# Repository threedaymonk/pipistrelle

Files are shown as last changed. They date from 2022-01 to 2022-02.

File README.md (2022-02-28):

# Pipistrelle

A low-cost multi-function Eurorack module based on the Seeeduino Xiao module.

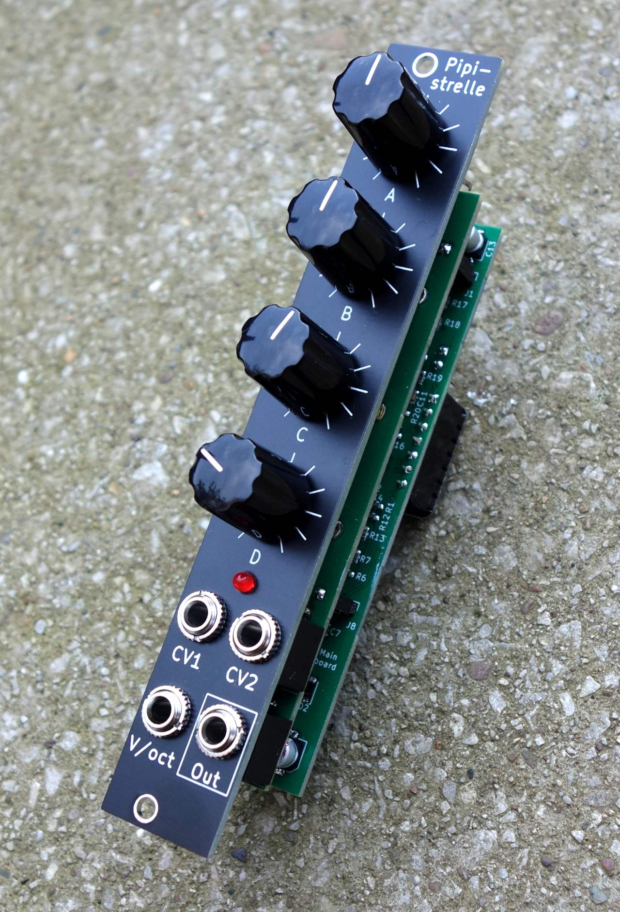
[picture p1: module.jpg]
Assembled module


This module can be built for as little as £20 (based on an order of 25 with
surface mount parts mostly assembled by JLCPCB) and provides:

- 4 potentiometers
- 2 CV inputs
- 1 V/oct input
- 1 DC-coupled output
- Output range ±5V or ±8V selected via jumper

Inputs are 12 bit, output is 10 bit.

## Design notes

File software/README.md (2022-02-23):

# Software for the Pipistrelle

All software is developed using [PlatformIO](https://platformio.org/) with the
Arduino toolchain for the Seeeduino Xiao.

# Calibration

To initiate calibration, turn all the pots to minimum, connect a patch cable
from **Out** to **CV1**, and power on the module.

The LED flashes.

Send 1V from a known source to **V/oct** and turn **A** fully clockwise.

The LED flashes twice.

Send 3V from a known source to **V/oct** and turn **B** fully clockwise.

The oscillator will now boot as normal.

## X-Y Oscillator

This oscillator generates sine, triangle, saw, and square waves and blends
between them using the C and D pots and CV inputs.

- **Pot A**: Coarse tune (C0 + 6 octaves)
- **Pot B**: Fine tune (+/- 1/2 octave)
- **Pot C + CV 1**: X
- **Pot D + CV 2**: Y

X and Y morph between waveforms thus:

     sine  --> triangle
      |           |
      v           v
    square -->   saw

## Supersaw

7 detuned saw waves and a square wave sub-oscillator an octave below

- **Pot A**: Coarse tune (C0 + 6 octaves)
- **Pot B**: Fine tune (+/- 1/2 octave)
- **Pot C + CV 1**: Detune amount
- **Pot D + CV 2**: Sub oscillator level

## Wavetable

Wavetable oscillator panning around 64 256-sample wavetables in an 8 by 8
plane.

- **Pot A**: Coarse tune (C0 + 6 octaves)
- **Pot B**: Fine tune (+/- 1/2 octave)
- **Pot C + CV 1**: X
- **Pot D + CV 2**: Y

## ADSR

ADSR envelope generator

- **Pot A**: Attack
- **Pot B + CV 1**: Decay
- **Pot C**: Sustain
- **Pot D + CV 2**: Release
- **V/oct**: Gate

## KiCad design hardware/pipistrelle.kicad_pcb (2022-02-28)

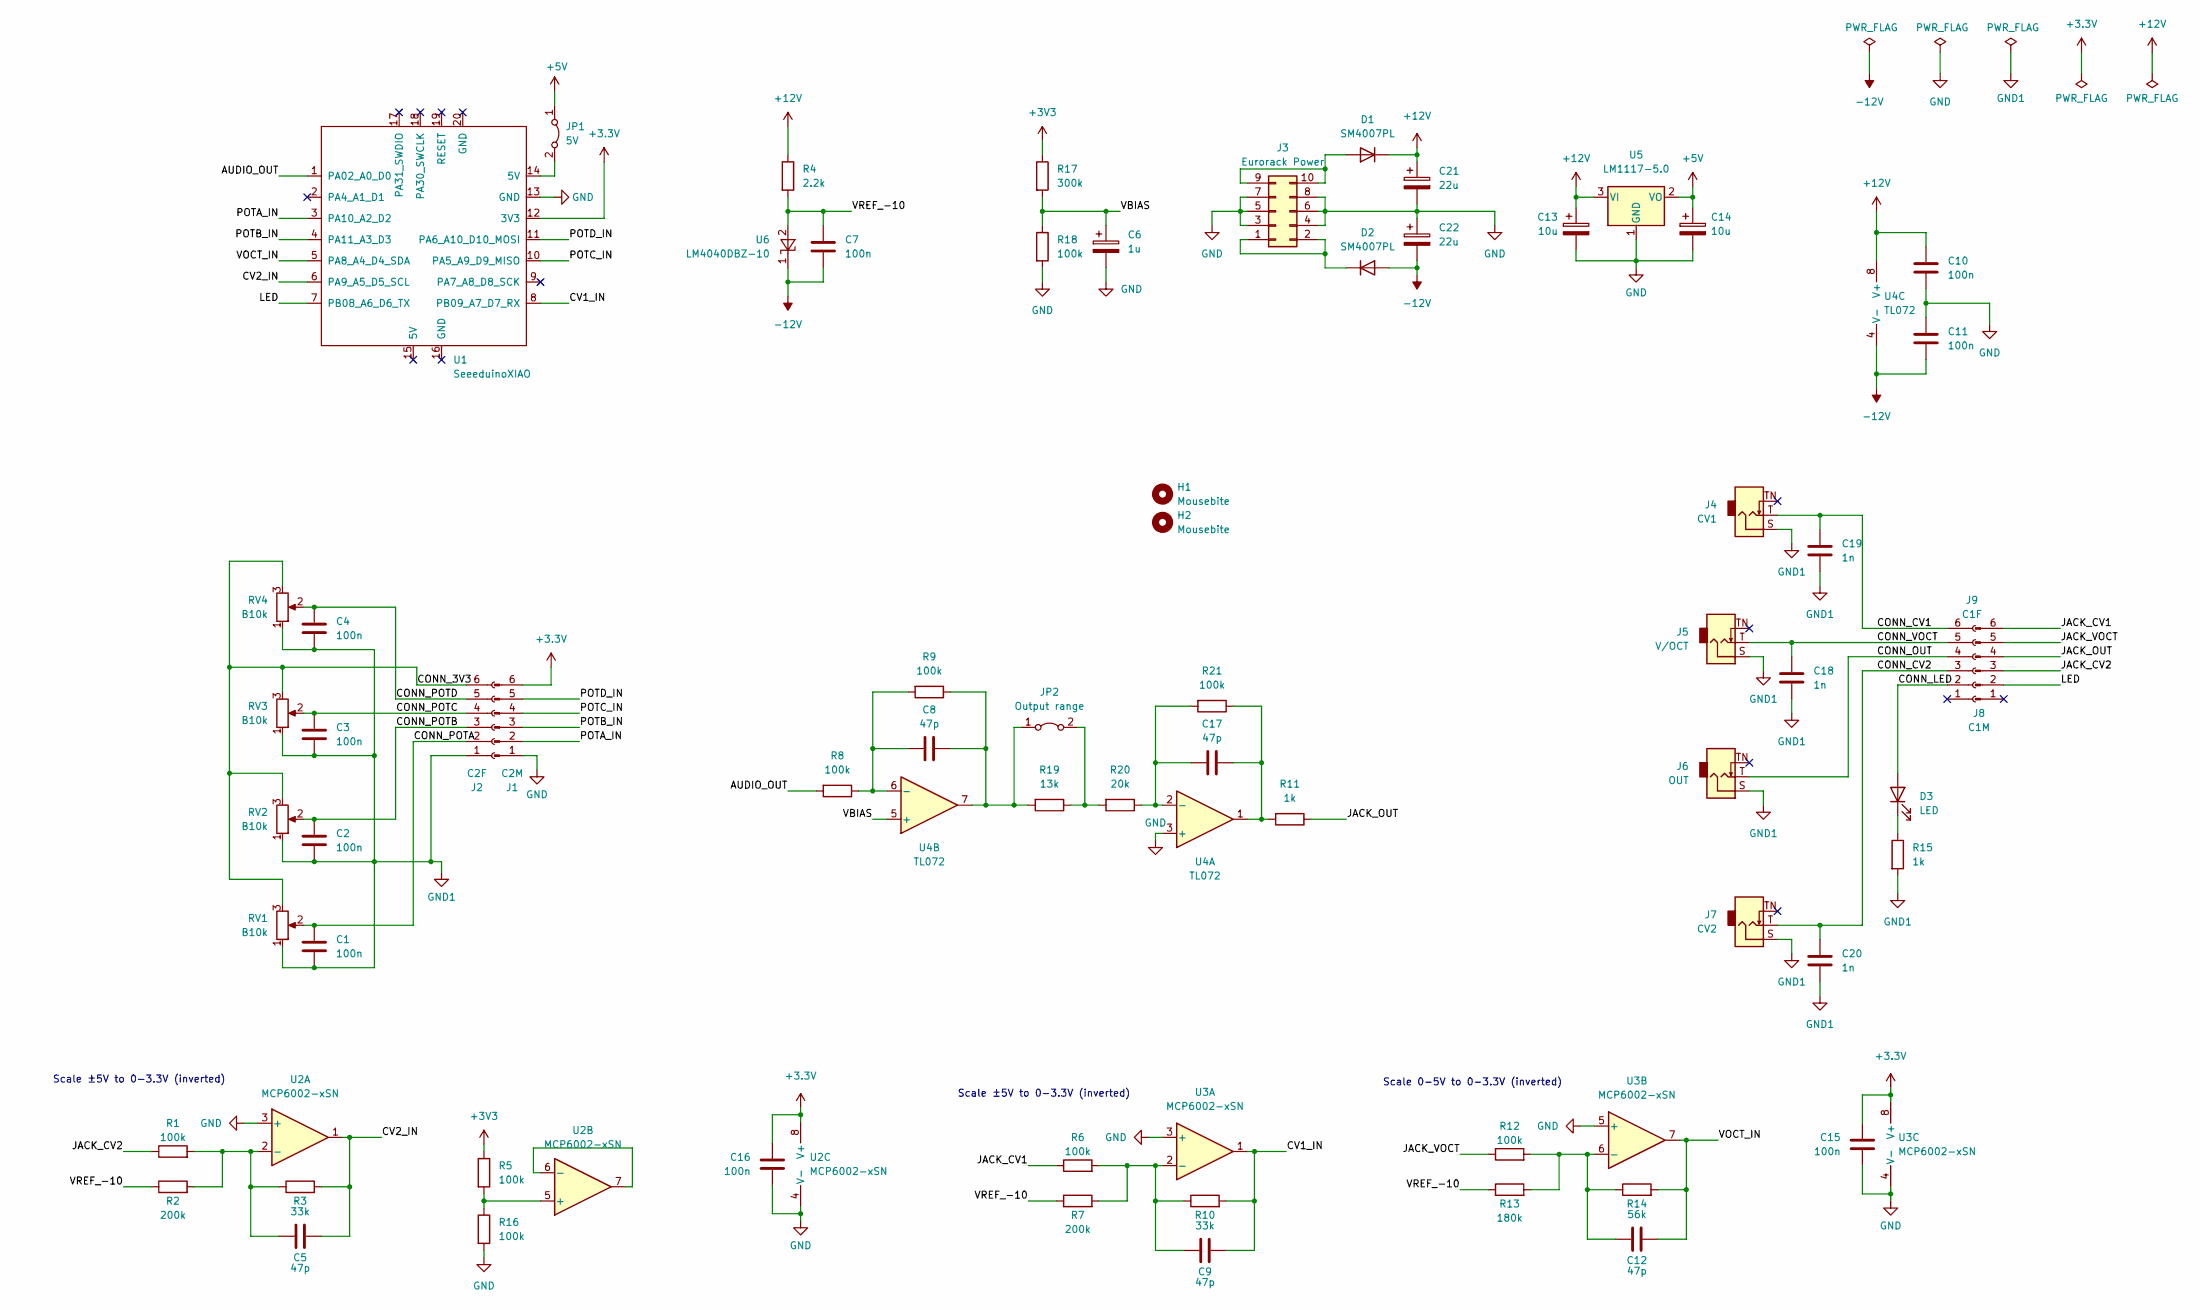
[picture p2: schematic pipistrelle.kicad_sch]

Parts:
C1, C2, C3, C4, C7, C10, C11, C15, C16: 100n; C_0603_1608Metric
C5, C8, C9, C12, C17: 47p; C_0603_1608Metric
C6: 1u; C_Elec_4x5.4; Mouser 667-EEE-HA1H1R0AR
C13, C14: 10u; C_Elec_4x5.4; Mouser 80-EEV106M035A9BAA
C18, C19, C20: 1n; C_1206_3216Metric
C21, C22: 22u; CP_Elec_5x5.9; Mouser 710-865060342002
D1, D2: SM4007PL; SOD-123FL
D3: LED; LED_D3.0mm
H1, H2: Mousebite; Mouse_bite_2x5mm
J1: C2M; PinHeader_1x06_P2.54mm_Vertical
J2: C2F; PinSocket_1x06_P2.54mm_Vertical
J3: Eurorack Power; Eurorack_10_pin_header
J4: CV1; Thonkiconn
J5: V/OCT; Thonkiconn
J6: OUT; Thonkiconn
J7: CV2; Thonkiconn
J8: C1M; PinHeader_1x06_P2.54mm_Vertical
J9: C1F; PinSocket_1x06_P2.54mm_Vertical
JP1: 5V; PinHeader_1x02_P2.54mm_Vertical
JP2: Output range; PinHeader_1x02_P2.54mm_Vertical
R1, R5, R6, R8, R9, R12, R16, R18, R21: 100k; R_0603_1608Metric
R2, R7: 200k; R_0603_1608Metric
R3, R10: 33k; R_0603_1608Metric
R4: 2.2k; R_0603_1608Metric
R11, R15: 1k; R_0603_1608Metric
R13: 180k; R_0603_1608Metric
R14: 56k; R_0603_1608Metric
R17: 300k; R_0603_1608Metric
R19: 13k; R_0603_1608Metric
R20: 20k; R_0603_1608Metric
RV1: B10k; Alpha_9mm_Pot_Overhanging
RV2, RV3, RV4: B10k; Alpha_9mm_Pot
U1: SeeeduinoXIAO; Seeeduino_XIAO_THT
U2, U3: MCP6002-xSN; SOIC-8_3.9x4.9mm_P1.27mm
U4: TL072; SOIC-8_3.9x4.9mm_P1.27mm
U5: LM1117-5.0; SOT-223-3_TabPin2
U6: LM4040DBZ-10; SOT-23; Mouser 926-LM4040DIM3100NPB

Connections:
+5V: C14.1, JP1.1 (A), U5.2 (VO)
+12V: C10.1, C13.1, C21.1, D1.1 (K), R4.1, U4.8 (V+), U5.3 (VI)
-12V: C7.2, C11.2, C22.2, D2.2 (A), U4.4 (V-), U6.1 (K)
/AUDIO_OUT: R8.2, U1.1 (PA02_A0_D0)
/CONN_3V3: J2.6, RV1.3, RV2.3, RV3.3, RV4.3
/CONN_CV1: C19.1, J4.T, J9.6
/CONN_CV2: C20.1, J7.T, J9.3
/CONN_LED: D3.2 (A), J9.2
/CONN_OUT: J6.T, J9.4
/CONN_POTA: C1.1, J2.2, RV1.2
/CONN_POTB: C2.1, J2.3, RV2.2
/CONN_POTC: C3.1, J2.4, RV3.2
/CONN_POTD: C4.1, J2.5, RV4.2
/CONN_VOCT: C18.1, J5.T, J9.5
/CV1_IN: C9.2, R10.2, U1.8 (PB09_A7_D7_RX), U3.1
/CV2_IN: C5.2, R3.2, U1.6 (PA9_A5_D5_SCL), U2.1
/JACK_CV1: J8.6, R6.1
/JACK_CV2: J8.3, R1.1
/JACK_OUT: J8.4, R11.1
/JACK_VOCT: J8.5, R12.1
/LED: J8.2, U1.7 (PB08_A6_D6_TX)
/POTA_IN: J1.2, U1.3 (PA10_A2_D2)
/POTB_IN: J1.3, U1.4 (PA11_A3_D3)
/POTC_IN: J1.4, U1.10 (PA5_A9_D9_MISO)
/POTD_IN: J1.5, U1.11 (PA6_A10_D10_MOSI)
/VBIAS: C6.1, R17.2, R18.1, U4.5 (+)
/VOCT_IN: C12.2, R14.2, U1.5 (PA8_A4_D4_SDA), U3.7
/VREF_-10: C7.1, R2.1, R4.2, R7.1, R13.1, U6.2 (A)
GND: C6.2, C10.2, C11.1, C13.2, C14.2, C15.2, C16.2, C21.2, C22.1, J1.1, J3.3, J3.4, J3.5, J3.6, J3.7, J3.8, R16.2, R18.2, U1.13 (GND), U2.3 (+), U2.4 (V-), U3.3 (+), U3.4 (V-), U3.5 (+), U4.3 (+), U5.1 (GND)
GND1: C1.2, C2.2, C3.2, C4.2, C18.2, C19.2, C20.2, J2.1, J4.S, J5.S, J6.S, J7.S, R15.2, RV1.1, RV2.1, RV3.1, RV4.1
unnamed: C5.1, R1.2, R2.2, R3.1, U2.2 (-)
unnamed: C8.1, JP2.1 (A), R9.1, R19.2, U4.7
unnamed: C8.2, R8.1, R9.2, U4.6 (-)
unnamed: C9.1, R6.2, R7.2, R10.1, U3.2 (-)
unnamed: C12.1, R12.2, R13.2, R14.1, U3.6 (-)
unnamed: C17.1, R11.2, R21.1, U4.1
unnamed: C17.2, R20.1, R21.2, U4.2 (-)
unnamed: D1.2 (A), J3.9, J3.10
unnamed: D2.1 (K), J3.1, J3.2
unnamed: D3.1 (K), R15.1
unnamed: JP1.2 (B), U1.14 (5V)
unnamed: JP2.2 (B), R19.1, R20.2
unnamed: R5.2, R16.1, U2.5 (+)
unnamed: U2.6 (-), U2.7

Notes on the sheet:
Scale ±5V to 0-3.3V (inverted)
Scale 0-5V to 0-3.3V (inverted)

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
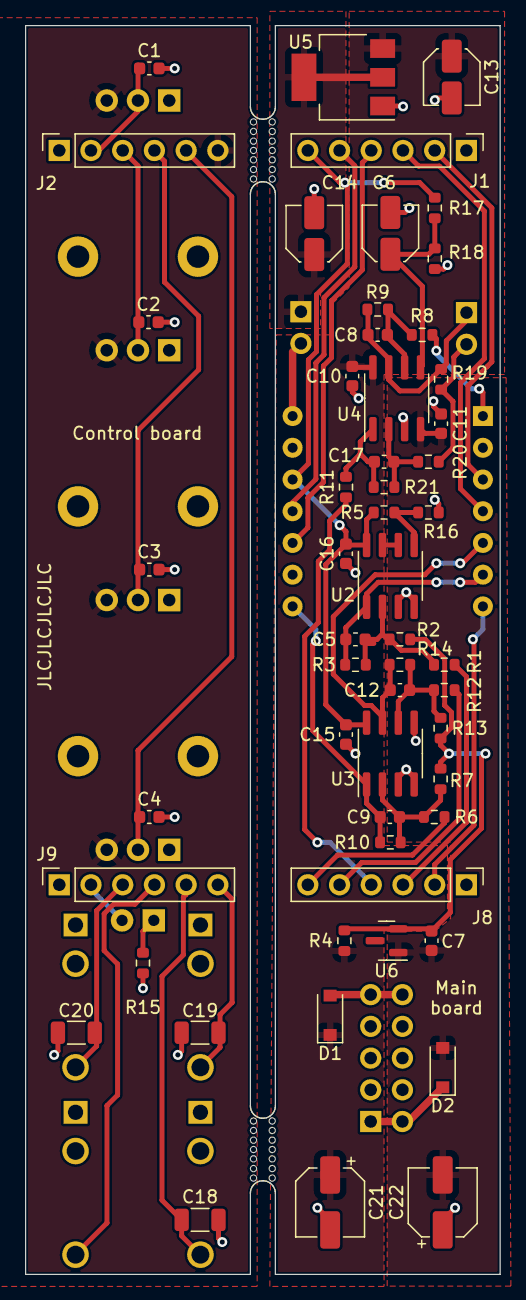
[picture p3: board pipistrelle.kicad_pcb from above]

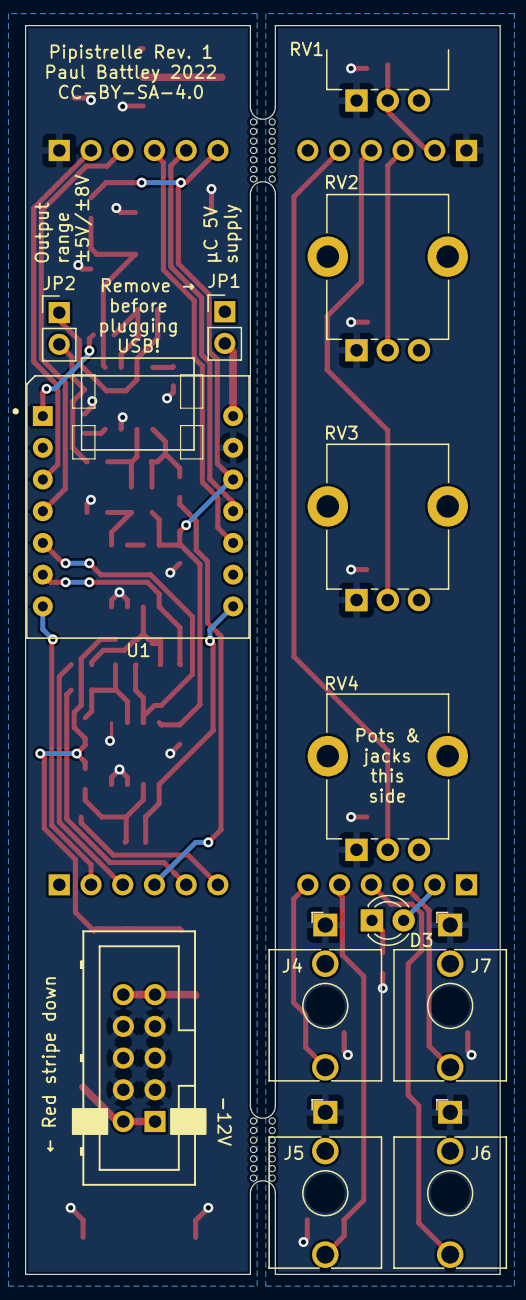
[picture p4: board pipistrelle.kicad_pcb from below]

Board: 2 copper layers, 38.0 x 100.0 mm, 69 parts (13 on the bottom side), 45 nets.

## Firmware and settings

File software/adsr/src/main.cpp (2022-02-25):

// ADSR
//
// Pot A => Attack
// Pot B + CV 1 => Decay
// Pot C => Sustain
// Pot D + CV 2 => Release
// V/oct => Gate input

#include <math.h>

#include <Pipistrelle/Device.h>
#include <Pipistrelle/Modulation.h>

#include "ADSR.h"

using fixed = fpm::fixed_16_16;
using namespace Pipistrelle::Modulation;

// Anything over about 1kHz is fine when our output resolution is 10 bits,
// but too low leads to visible LED flicker.
const int sampleRate = 8000;

const double minA = 0.0002L,
             maxA = 12.0L,
             minDR = 0.001L,
             maxDR = 15.0L,
             controlExp = 2.0L;

Pipistrelle::Device *pip;
ADSR *env;

void setup() {
  env = new ADSR();
  pip = new Pipistrelle::Device(sampleRate);
}

void loop() {
  static bool old_gate = false;

  bool gate = pip->gate3();

  // Scale pots using an exponential curve. This allows a wider range while
  // still providing fine control at lower levels.
  // Technically, the range is min to (min + max), but as the max values are
  // so much larger, the difference is insignificant.
  double a = pow(unipolar(pip->pota()), controlExp)
           * maxA + minA;
  double d = pow(unipolarPotWithCV(pip->potb(), pip->cv1()), controlExp)
           * maxDR + minDR;
  double s = unipolar(pip->potc());
  double r = pow(unipolarPotWithCV(pip->potd(), pip->cv2()), controlExp)
           * maxDR + minDR;

  env->setAttackRate(a * sampleRate);
  env->setDecayRate(d * sampleRate);
  env->setSustainLevel(s);
  env->setReleaseRate(r * sampleRate);

  if (gate != old_gate) {
    env->gate(gate);
    old_gate = gate;
  }
}

void TC4_Handler() {
  static int counter = 0;

  double level = env->process();

  int sample = 511 + 512 * level;
  pip->dacWrite(sample);

  // Manually PWM the LED. We don't use analogWrite because that kills
  // operation (reason unknown, possibly due to interrupt use)
  pip->led(counter < ((sample - 512) >> 2));
  counter = (counter + 1) % 128;

  REG_TC4_INTFLAG = TC_INTFLAG_OVF; // clear interrupt overflow flag
}

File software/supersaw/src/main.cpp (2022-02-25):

// Supersaw
//
// Pot A => Coarse tune (C0 + 6 octaves)
// Pot B => Fine tune (+/- 1/2 octave)
// Pot C + CV 1 => Detune
// Pot D + CV 2 => Sub oscillator level

#include <fpm/fixed.hpp>
#include <fpm/math.hpp>

#include <Pipistrelle/Device.h>
#include <Pipistrelle/Waveform.h>
#include <Pipistrelle/Modulation.h>

using fixed = fpm::fixed_16_16;
using namespace Pipistrelle::Waveform;
using namespace Pipistrelle::Modulation;

const int sampleRate = 32000;
const float C0 = 16.3516f;
const int numSaws = 7;
// Pleasing weighting determined through trial and error
const int sawMix[numSaws] = {3, 4, 5, 6, 5, 4, 3};
const fixed F0 = static_cast<fixed>(0);

fixed sawPhi[numSaws], subPhi, subLevel;
int sawDivisor = 0;

Pipistrelle::Device *pip;

void setup() {
  // Compute the weighting divisor once
  for (int i = 0; i < numSaws; i++) sawDivisor += sawMix[i];
  pip = new Pipistrelle::Device(sampleRate);
  pip->led(true);  // Shows that we got this far
}

fixed nextSample() {
  static fixed sawTheta[numSaws] = {F0, F0, F0, F0, F0, F0, F0},
               subTheta = F0;
  fixed sample = F0, subSample;

  for (int i = 0; i < numSaws; i++) {
    sample += saw(sawTheta[i]) * sawMix[i];
    sawTheta[i] = fpm::fmod(sawTheta[i] + sawPhi[i], static_cast<fixed>(1));
  }

  subSample = square(subTheta);
  subTheta = fpm::fmod(subTheta + subPhi, static_cast<fixed>(1));

  return blend(subLevel, sample / sawDivisor, subSample);
}

void loop() {
  float voct = pip->voct()
             + 6.0F * unipolar(pip->pota())  // coarse tuning
             + unipolar(pip->potb()) / 2.0F;  // fine tuning

  float frequency = C0 * pow(2, voct);

  float detune = frequency / 80
               * unipolarPotWithCV(pip->potc(), pip->cv1());

  subLevel = static_cast<fixed>(0.25f * unipolarPotWithCV(pip->potd(), pip->cv2()));

  for (int i = 0; i < numSaws; i++) {
    float f = frequency + detune * (i - numSaws / 2);
    sawPhi[i] = static_cast<fixed>(f / sampleRate);
  }

  subPhi = static_cast<fixed>(frequency / (2 * sampleRate));
}

void TC4_Handler() {
  pip->dacWrite(nextSample());
  REG_TC4_INTFLAG = TC_INTFLAG_OVF;  // clear interrupt overflow flag
}

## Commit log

2022-01-01 In progress
    [xiao-vco.kicad_pcb, xiao-vco.kicad_sch]
2022-01-01 Import JLCPCB design rules
    From https://github.com/sethhillbrand/kicad_templates
    [xiao-vco.kicad_pcb]
2022-01-02 First completed routing
    [xiao-vco.kicad_pcb, xiao-vco.kicad_sch]
2022-01-02 Routed all on one face
    [xiao-vco.kicad_pcb, xiao-vco.kicad_sch]
2022-01-02 Components now face inwards
    [xiao-vco.kicad_pcb, xiao-vco.kicad_sch]
2022-01-02 Automate Gerber zipping
2022-01-02 Use SMD diodes
    [xiao-vco.kicad_pcb, xiao-vco.kicad_sch]
2022-01-03 Change MCP6004 to 6002 for availability
    JLCPCB has MCP6002 in basic range.
    [xiao-vco.kicad_pcb, xiao-vco.kicad_sch]
2022-01-03 Flip control board for SMD assembly
    [xiao-vco.kicad_pcb]
2022-01-03 Add LED
    [xiao-vco.kicad_pcb, xiao-vco.kicad_sch]
2022-01-03 Simulate output circuit
    [output.kicad_sch]
2022-01-04 Add switchable 5/8V output
    [xiao-vco.kicad_pcb, xiao-vco.kicad_sch]
2022-01-05 Update text
    [xiao-vco.kicad_pcb]
2022-01-05 Tweak layout, fix CV gain
    [xiao-vco.kicad_pcb, xiao-vco.kicad_sch]
2022-01-05 Remove Makefile for Gerbers
2022-01-05 Use Bouni's JLCPCB tools
    https://github.com/Bouni/kicad-jlcpcb-tools
2022-01-05 Give it a name: Pipistrelle
    [output.kicad_sch, pipistrelle.kicad_pcb, pipistrelle.kicad_sch]
2022-01-08 Added power caps
    [pipistrelle.kicad_pcb, pipistrelle.kicad_sch]
2022-01-08 Keep ground plane out from under jacks
    [pipistrelle.kicad_pcb]
2022-01-08 Tidied up edge cuts
    Some weird .999999 measurements had crept in.
    [pipistrelle.kicad_pcb]
2022-01-08 Add a panel
    [panel.kicad_pcb]
2022-01-08 Make this project its own repository
    [output.kicad_sch, panel.kicad_pcb, pipistrelle.kicad_pcb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]
2022-01-13 Use 1k for LED resistor
    Tested, and plenty bright enough.
    [pipistrelle.kicad_pcb, pipistrelle.kicad_sch]
2022-01-13 Update footprints
    Mouse bites are now in the schematic so they won't disappear on update
    [pipistrelle.kicad_pcb, pipistrelle.kicad_sch]
2022-01-13 Update panel footprints
    Holes are now 1mm higher
    [panel.kicad_pcb]
2022-01-14 Change ESD cap to 1206
    The 0603 I intended to use is unavailable at JLC, and there's plenty of
    space.
    [pipistrelle.kicad_pcb, pipistrelle.kicad_sch]
2022-01-14 Ignore PCB files symlinked for convenience
2022-01-14 Update filled region on panel
    [panel.kicad_pcb]
2022-02-10 Use ABCD for pot designations as front panel
    [pipistrelle.kicad_pcb, pipistrelle.kicad_sch]
2022-02-10 Correct output offset
    [pipistrelle.kicad_sch]
2022-02-10 Use more common values for offset divider
    Neither 110 nor 300 are E12, but 100 is E6.
    [pipistrelle.kicad_pcb, pipistrelle.kicad_sch]
2022-02-10 Test program with calibration
2022-02-10 Hard-code calibration for now
    Flash is wiped on every upload, and I don't want to recalibrate each
    time.
2022-02-10 Pitch now matches expected intput
    We have a really small time budget for each sample, so we can't afford
    to calculate anything in real time, and expecially not floating point
    functions.
2022-02-13 Stabilise ADC readings by repeating 32x
2022-02-13 Test program is now XY oscillator
    [xy-oscillator.ino]
2022-02-13 Increase sample rate to 48kHz
    It seems to manage happily
2022-02-13 Move sample rate setup to dac_setup
2022-02-16 Use raw ADC in calibration
2022-02-16 Specify accuracy of ADC
    This allows us to save time when reading values where we don't care about
    fluctuation.
2022-02-16 Updaate XY oscillator with buffer and ADC accuracy
    [xy-oscillator.ino]
2022-02-19 Smaller buffer, lower latency
    90ms was too much.
    [main.cpp]
2022-02-19 Fix oscillator mix algorithm
    It now works as I intended, but I'm still not sure I want anything less
    than all on.
    [main.cpp]
2022-02-19 1:3 sub oscillator mix is plenty
    [main.cpp]
2022-02-19 Use ResponsiveAnalogRead to handle ADC jitter
    https://github.com/dxinteractive/ResponsiveAnalogRead
    Pipistrelle is now a C++ class.
    [main.cpp, xy-oscillator.ino]
2022-02-20 Make Calibrator a class
2022-02-20 Calculate sample using phase shift per sample
    The previous method only worked at frequencies significantly below the
    sample rate.
2022-02-20 Working wavetable oscillator
    Samples from the PISTON_H.WAV set from http://waveeditonline.com/
    [main.cpp]
2022-02-20 Move hardware to hardware directory
    [output.kicad_sch, panel.kicad_pcb, pipistrelle.kicad_pcb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]
2022-02-21 Add analogue LED facility
2022-02-22 Constrain LED to 0-255 brightness
2022-02-23 Reduce sample rate
    Anything more than about 1000kHz is unnecessary given the output range,
    but this is fast enough that the LED PWM still looks good.
2022-02-23 Use doubles because the ADSR lib does
    ... and the ADSR lib uses them in order to avoid coefficient being
    miscalculated as 1.
    [main.cpp]
2022-02-25 Move writing fixed point to Device
2022-02-25 Update oscillators and ADSR for new platform
    Everything is now slightly more idiomatic C++, and fixed-point maths
    uses the fpm library.
    [main.cpp]
2022-02-28 Remove model schematic, as it's distracting
    This was used to test resistor values.
    [output.kicad_sch]
2022-02-28 Upgrade part number for R17 and R18
    [pipistrelle.kicad_pcb]

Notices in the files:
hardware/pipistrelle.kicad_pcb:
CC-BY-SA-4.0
